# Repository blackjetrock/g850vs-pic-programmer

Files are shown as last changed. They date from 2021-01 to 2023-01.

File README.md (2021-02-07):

# g850vs-pic-programmer
PIC programmer for G850VS

These are the files for a PIC programmer for a Sharp PC-G850V or PC-G850VS pocket computer.
The PIC programmer is from a ciruit i found on the internet. I have had permission to use the circuit
so that people can use it to program PICs. 

The PIC prototype PCB is based on the test circuit in the PC-G850 manual, except that, for some reaosn,
I changed the GPIO line that the LED is driven from. The example program given in the manual will have to 
be adjusted appropriately.

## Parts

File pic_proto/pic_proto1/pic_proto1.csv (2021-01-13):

Id | Designator | Package | Quantity | Designation | Supplier and ref
1 | REF** | Molex_KK-254_AE-6410-08A_1x08_P2.54mm_Vertical | 1 | Molex_KK-254_AE-6410-08A_1x08_P2.54mm_Vertical
2 | X1 | Crystal_HC49-4H_Vertical | 1 | XTAL
3 | U1 | DIP-18_W7.62mm | 1 | PIC16F84A-XXP
4 | SW1 | SW_PUSH-12mm | 1 | Switch_SW_SPST
5 | R2 | R_Axial_DIN0204_L3.6mm_D1.6mm_P7.62mm_Horizontal | 1 | 330R
6 | R1 | R_Axial_DIN0204_L3.6mm_D1.6mm_P7.62mm_Horizontal | 1 | 10k
7 | J2 | Molex_KK-254_AE-6410-11A_1x11_P2.54mm_Vertical | 1 | Conn_01x11
8 | J1 | Molex_KK-254_AE-6410-04A_1x04_P2.54mm_Vertical | 1 | Conn_01x04_Male
9 | D1 | LED_D5.0mm | 1 | LED
10 | C2,C1 | C_Disc_D7.5mm_W5.0mm_P5.00mm | 2 | 22pF

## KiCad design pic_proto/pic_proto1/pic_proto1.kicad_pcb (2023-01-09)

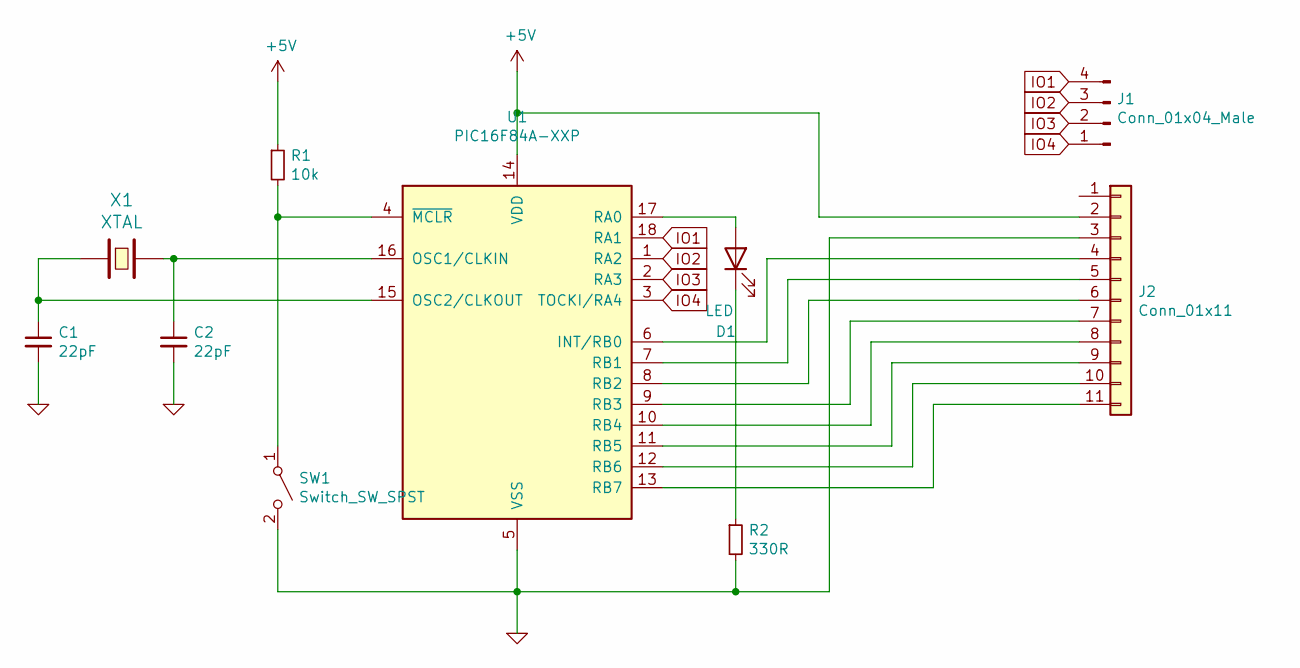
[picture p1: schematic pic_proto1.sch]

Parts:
C1, C2: 22pF; C_Disc_D7.5mm_W5.0mm_P5.00mm
D1: LED; LED_D5.0mm
J1: Conn_01x04_Male; Molex_KK-254_AE-6410-04A_1x04_P2.54mm_Vertical
J2: Conn_01x11; Molex_KK-254_AE-6410-11A_1x11_P2.54mm_Vertical
R1: 10k; R_Axial_DIN0204_L3.6mm_D1.6mm_P7.62mm_Horizontal
R2: 330R; R_Axial_DIN0204_L3.6mm_D1.6mm_P7.62mm_Horizontal
SW1: Switch_SW_SPST; SW_PUSH-12mm
U1: PIC16F84A-XXP; DIP-18_W7.62mm
X1: XTAL; Crystal_HC49-4H_Vertical

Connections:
+5V: J2.2, R1.1, U1.14 (VDD)
GND: C1.2, C2.2, J2.3, R2.2, SW1.2 (B), U1.5 (VSS)
IO1: J1.4, U1.18 (RA1)
IO2: J1.3, U1.1 (RA2)
IO3: J1.2, U1.2 (RA3)
IO4: J1.1, U1.3 (TOCKI/RA4)
unnamed: C1.1, U1.15 (OSC2/CLKOUT), X1.1
unnamed: C2.1, U1.16 (OSC1/CLKIN), X1.2
unnamed: D1.1 (K), R2.1
unnamed: D1.2 (A), U1.17 (RA0)
unnamed: J2.4, U1.6 (INT/RB0)
unnamed: J2.5, U1.7 (RB1)
unnamed: J2.6, U1.8 (RB2)
unnamed: J2.7, U1.9 (RB3)
unnamed: J2.8, U1.10 (RB4)
unnamed: J2.9, U1.11 (RB5)
unnamed: J2.10, U1.12 (RB6)
unnamed: J2.11, U1.13 (RB7)
unnamed: R1.2, SW1.1 (A), U1.4 (~MCLR~)

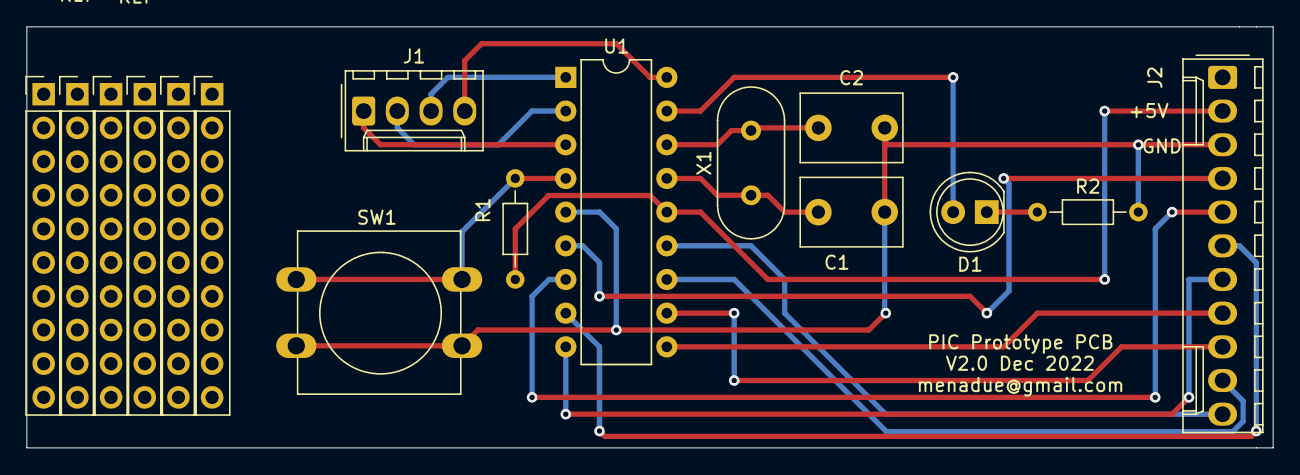
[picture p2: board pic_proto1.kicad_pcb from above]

Board: 2 copper layers, 94.0 x 31.8 mm, 10 parts (0 on the bottom side), 19 nets.

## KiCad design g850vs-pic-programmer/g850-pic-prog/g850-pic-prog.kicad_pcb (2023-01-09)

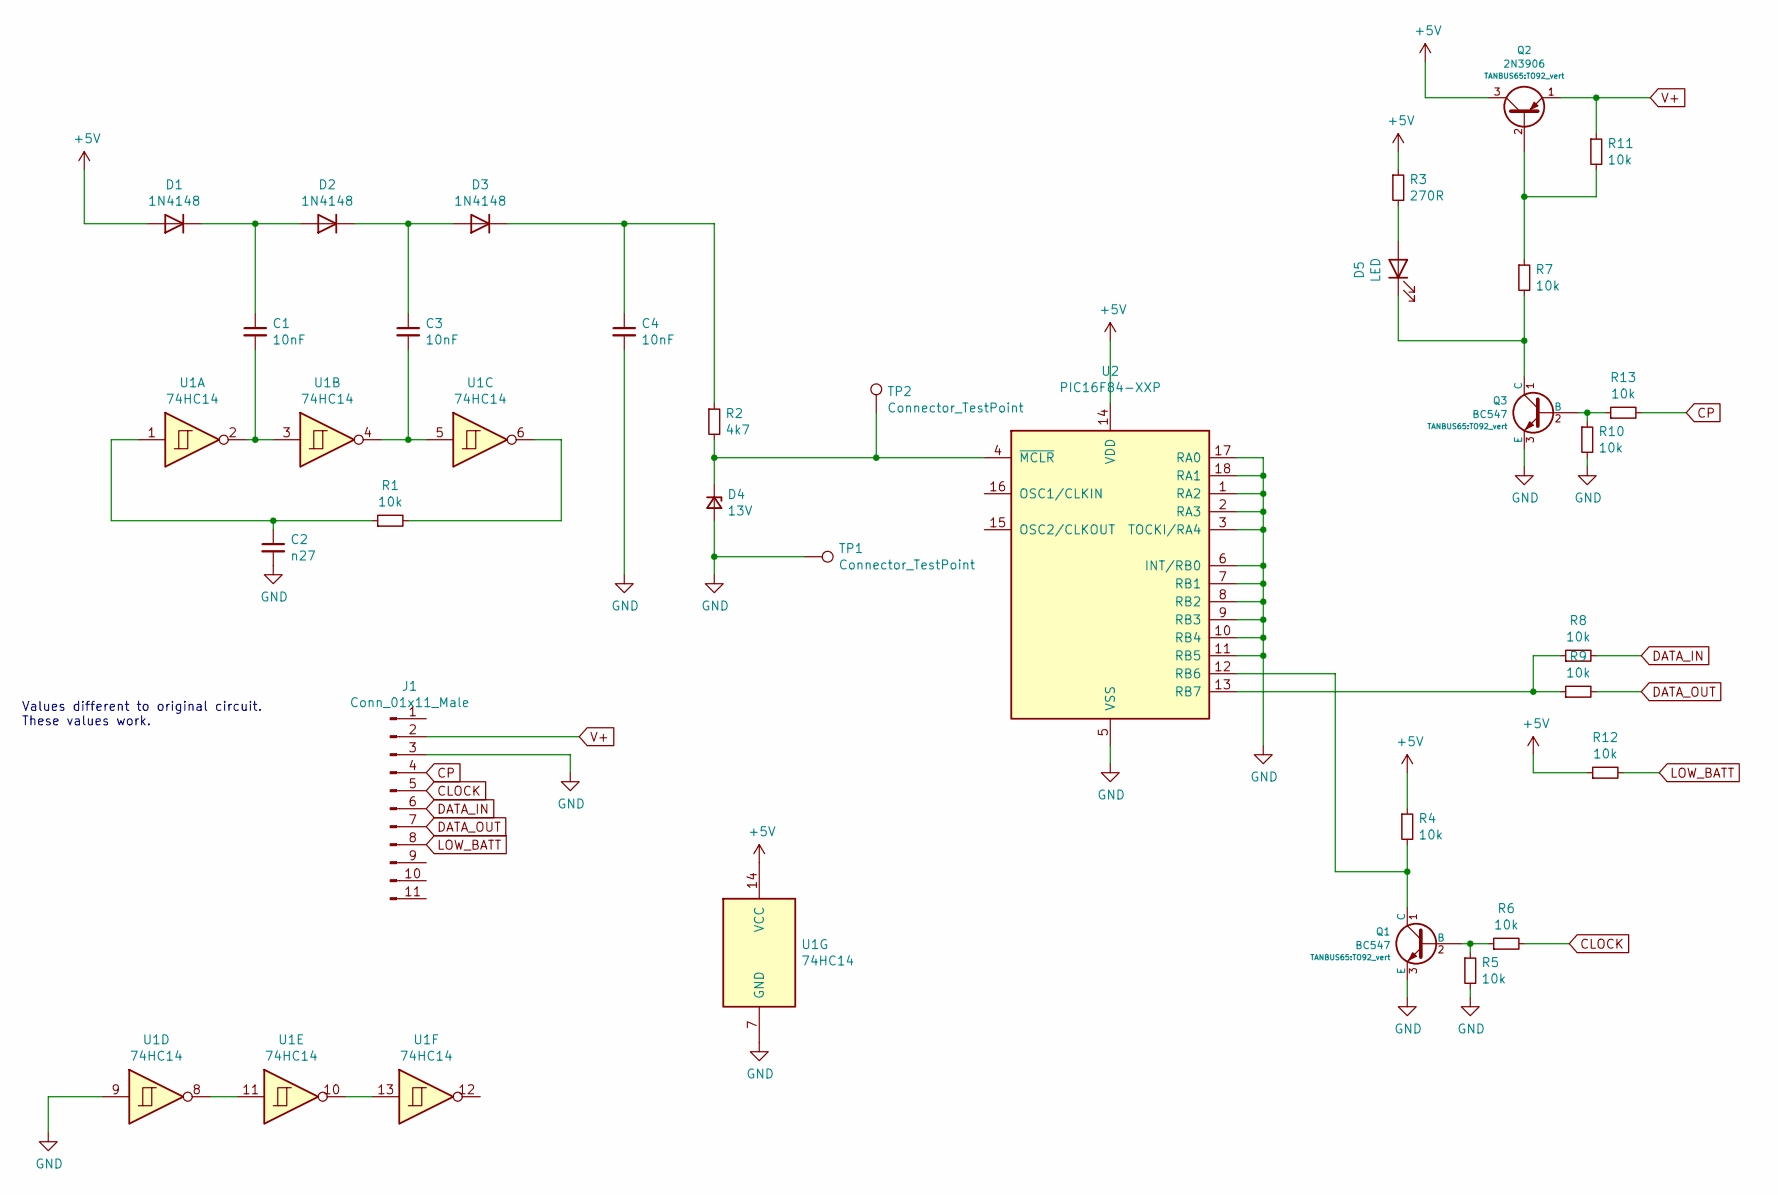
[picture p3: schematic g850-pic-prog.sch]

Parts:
C1, C3, C4: 10nF; C_Axial_L5.1mm_D3.1mm_P7.50mm_Horizontal
C2: n27; C_Axial_L5.1mm_D3.1mm_P7.50mm_Horizontal
D1, D2, D3: 1N4148; D_DO-35_SOD27_P7.62mm_Horizontal
D4: 13V; D_DO-35_SOD27_P7.62mm_Horizontal
D5: LED; LED_D5.0mm
J1: Conn_01x11_Male; Molex_KK-254_AE-6410-11A_1x11_P2.54mm_Vertical
Q1, Q3: BC547; TO92_vert
Q2: 2N3906; TO92_vert
R1, R4, R5, R6, R7, R8, R9, R10, R11, R12, R13: 10k; R_Axial_DIN0207_L6.3mm_D2.5mm_P7.62mm_Horizontal
R2: 4k7; R_Axial_DIN0207_L6.3mm_D2.5mm_P7.62mm_Horizontal
R3: 270R; R_Axial_DIN0207_L6.3mm_D2.5mm_P7.62mm_Horizontal
TP1, TP2: Connector_TestPoint; TestPoint_Loop_D1.80mm_Drill1.0mm_Beaded
U1: 74HC14; DIP-14_W7.62mm
U2: PIC16F84-XXP; DIP_Socket-18_W4.3_W5.08_W7.62_W10.16_W10.9_3M_218-3341-00-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

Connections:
+5V: D1.2 (A), Q2.3 (C), R3.1, R4.1, R12.1, U1.14 (VCC), U2.14 (VDD)
CLOCK: J1.5, R6.2
CP: J1.4, R13.2
DATA_IN: J1.6, R8.2
DATA_OUT: J1.7, R9.2
GND: C2.2, C4.2, D4.2 (A), J1.3, Q1.3 (E), Q3.3 (E), R5.2, R10.2, TP1.1, U1.7 (GND), U1.9, U2.1 (RA2), U2.2 (RA3), U2.3 (TOCKI/RA4), U2.5 (VSS), U2.6 (INT/RB0), U2.7 (RB1), U2.8 (RB2), U2.9 (RB3), U2.10 (RB4), U2.11 (RB5), U2.17 (RA0), U2.18 (RA1)
LOW_BATT: J1.8, R12.2
unnamed: C1.1, D1.1 (K), D2.2 (A)
unnamed: C1.2, U1.2, U1.3
unnamed: C2.1, R1.1, U1.1
unnamed: C3.1, D2.1 (K), D3.2 (A)
unnamed: C3.2, U1.4, U1.5
unnamed: C4.1, D3.1 (K), R2.1
unnamed: D4.1 (K), R2.2, TP2.1, U2.4 (~MCLR~)
unnamed: D5.1 (K), Q3.1 (C), R7.2
unnamed: D5.2 (A), R3.2
unnamed: Q1.1 (C), R4.2, U2.12 (RB6)
unnamed: Q1.2 (B), R5.1, R6.1
unnamed: Q2.2 (B), R7.1, R11.2
unnamed: Q3.2 (B), R10.1, R13.1
unnamed: R1.2, U1.6
unnamed: R8.1, R9.1, U2.13 (RB7)
unnamed: U1.10, U1.13
unnamed: U1.8, U1.11
V+: J1.2, Q2.1 (E), R11.1

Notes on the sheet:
Values different to original circuit. These values work.

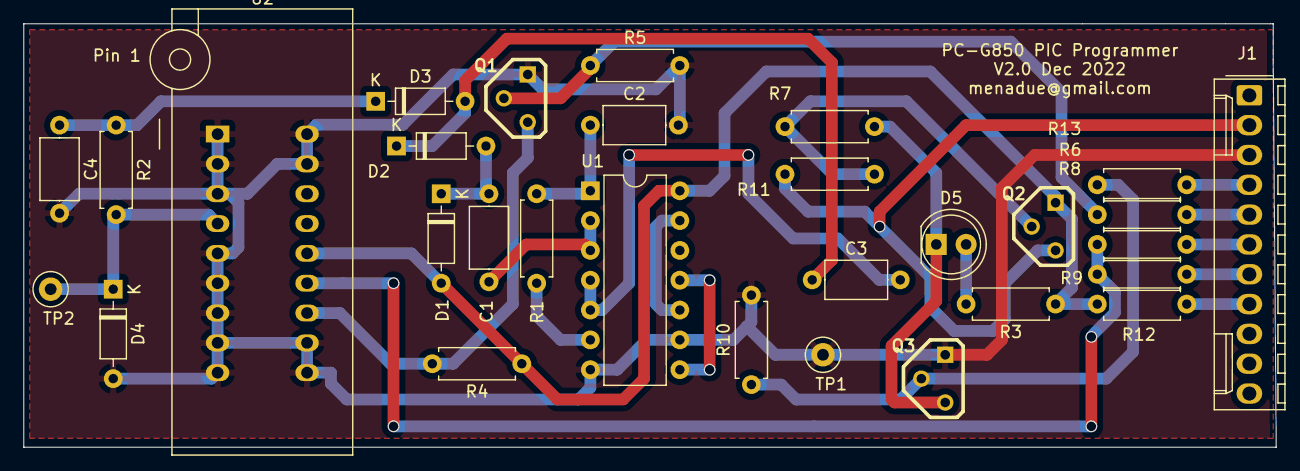
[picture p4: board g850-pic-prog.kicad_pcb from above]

Board: 2 copper layers, 106.7 x 36.1 mm, 30 parts (0 on the bottom side), 25 nets.

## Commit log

2021-01-13 Added PIC programmer and PIC prototype PCB files.
    [g850-pic-prog-B_Cu.gbr, g850-pic-prog-B_Mask.gbr, g850-pic-prog-B_Paste.gbr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]
2021-02-07 Updated values on PIC programmer to get one of my PCBs working. Capacitor values don't seem to be correct on original circuit.
    [g850-pic-prog.sch]
2021-02-07 C2 should be n27, or 270pF. 10nF does not work.
    [g850-pic-prog.sch]
